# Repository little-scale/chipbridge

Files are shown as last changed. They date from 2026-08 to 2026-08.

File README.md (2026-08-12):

# Chipbridge

Chipbridge is a shared RP2040-based MIDI and synchronisation interface for
retro-console music systems. A common RP2040-Zero board provides USB MIDI,
opto-isolated serial MIDI, status indication, and a protected two-wire console
interface. Console-specific cables and passive adapters connect that interface
to supported systems.

This repository owns the shared Chipbridge hardware and RP2040 firmware. Atari
Lynx and Atari 2600 firmware remain in their respective software projects; this
repository contains only their applicable shared hardware and adapters.

## Compatibility

In this table, **Sync** means synchronisation from MIDI Clock. **Notes** means
MIDI note events are delivered to the relevant tracker channel or instrument
inputs.

| Console | Software | Sync | Notes | PCB | Firmware | Control input | Test |
|---|---|---:|---:|---|---|---|---|
| Sega Master System | [SMSGGDJ tracker](https://github.com/little-scale/smsggdj) | Yes | Yes | Shared | Shared | Sega 9-pin | OK |
| Mega Drive / Genesis | [genmddj tracker](https://github.com/little-scale/genmddj) | Yes | Yes | Shared | Shared | Sega 9-pin | OK |
| Game Gear | [SMSGGDJ tracker](https://github.com/little-scale/smsggdj) | Yes | Yes | Shared | Shared | Game Gear sync PCB | OK |
| Atari Lynx | [alynxdj tracker](https://github.com/little-scale/alynxdj) | Yes | Yes | Shared | Target-specific | 2.5 mm cable | OK |
| Super Nintendo | [SNDJ tracker](https://github.com/little-scale/sndj) | Yes | No | Shared | Shared | SNES cable | OK |
| Atari 2600 | [a26f-neo interface](https://github.com/little-scale/a26f-neo) | No | Yes | Shared | Target-specific | Atari 9-pin PCB | OK |

“Shared” means the component is maintained in Chipbridge. Target-specific
firmware remains in its console software project. See the
[`compatibility notes`](docs/COMPATIBILITY.md) for the ownership boundary.

For Wi-Fi Ableton Link rather than wired MIDI, see the complementary
[SMSGGDJ Link ESP32 bridge](https://github.com/little-scale/smsggdj-link-esp32).

## Repository layout

- `firmware/rp2040/` — shared Pico-family firmware and build instructions.
- `hardware/main/` — the RP2040-Zero Chipbridge board; see the
  [bill of materials](hardware/BOM.md).
- `hardware/adapters/` — console connector and cable adapter PCBs.
- `docs/` — MIDI protocol, serial-MIDI circuit, and wiring documentation.
- `releases/rp2040/` — current prebuilt UF2 images.
- `tests/` — host-side protocol/parser tests.
- `tools/` — reproducible release builders.

## Licensing

- Hardware designs: CERN-OHL-P-2.0.
- Firmware, tools, tests, and corresponding UF2 binaries: GPL-2.0-only.
- Documentation: CC BY 4.0.

See [`LICENSE.md`](LICENSE.md) for the precise scope, attribution, and licence
texts.

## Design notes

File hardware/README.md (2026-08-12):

# Chipbridge hardware

## Projects

- `main/` — shared RP2040-Zero Chipbridge board.
- `adapters/game-gear/` — Game Gear EXT-port adapter.
- `adapters/sega-9pin/` — Sega 9-pin controller-port adapter.
- `adapters/atari-9pin/` — Atari 9-pin adapter.

Each directory contains the editable KiCad project, schematic, and PCB layout.
KiCad automatic backups, lock files, history, and per-user project state are
intentionally excluded.

## Bill of materials

See the [Chipbridge bill of materials](BOM.md) for the main board and adapter
parts lists. Price-free CSV exports are also provided alongside each KiCad
project. The component properties in the schematics are the source of truth.

## Project-local libraries

The main board uses a custom Waveshare RP2040-Zero symbol and footprint under
`libraries/`. Its `sym-lib-table` and `fp-lib-table` use `${KIPRJMOD}` relative
paths while retaining the original library nicknames used by the schematic and
PCB. No global or user-specific KiCad library entry is required.

The adapter projects currently use standard KiCad libraries only.

## Licensing

The KiCad schematics, PCB layouts, and project-local hardware libraries in
this directory are licensed under the permissive
[CERN Open Hardware Licence Version 2 – Permissive](LICENSE-CERN-OHL-P-2.0.txt),
SPDX identifier `CERN-OHL-P-2.0`.

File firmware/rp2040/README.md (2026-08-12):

# Chipbridge RP2040 firmware

The firmware source is licensed under GPL-2.0-only; see
[`../LICENSE-GPL-2.0.txt`](../LICENSE-GPL-2.0.txt).

This Arduino sketch supports:

- Raspberry Pi Pico (RP2040)
- Raspberry Pi Pico 2 (RP2350)
- Raspberry Pi Pico 2W (RP2350; Wi-Fi is deliberately unused)
- Waveshare RP2040-Zero
- Seeed XIAO RP2040

It is a wired MIDI device, not an Ableton Link client. MIDI can arrive as
class-compliant USB MIDI from a computer/DAW or as opto-isolated five-pin
DIN/TRS MIDI on an RX-only serial input. The general firmware in
`releases/rp2040/` contains both wire roles:

- MIDI Clock plus Start/Continue/Stop drives the rolling 2-bit `SYNC: IN24`
  counter.
- A MIDI channel message switches the same pins to the flag-framed,
  console-clocked stream used by `SYNC: MIDI`. Note on/off, CC, program change,
  pitch bend, and panic are forwarded.

While in takeover, continued console CLK polling keeps that role latched even
when a note is held and no new MIDI bytes arrive. If both channel traffic and
console polling stop for 500 ms, the firmware safely returns to the counter.

## Pinout

The pinout intentionally matches the **non-inverted logic output** documented
in `sms_tracker/adapter`:

| Board | counter bit 0 / takeover CLK | counter bit 1 / takeover DAT | Ground | Game Gear EXT / Sega DE-9 |
|---|---|---|---|---|
| Raspberry Pi Pico | GP0, physical pin 1 | GP1, physical pin 2 | physical pin 3 or any GND | pins 9 / 7 / 8 |
| Raspberry Pi Pico 2 | GP0, physical pin 1 | GP1, physical pin 2 | physical pin 3 or any GND | pins 9 / 7 / 8 |
| Raspberry Pi Pico 2W | GP0, physical pin 1 | GP1, physical pin 2 | physical pin 3 or any GND | pins 9 / 7 / 8 |
| Waveshare RP2040-Zero | GP0 | GP1 | any GND | pins 9 / 7 / 8 |
| Seeed XIAO RP2040 | D6 / GP0 | D7 / GP1 | GND | pins 9 / 7 / 8 |

In the final column, pin 9 is PC5/TR (bit 0/CLK), pin 7 is PC6/TH
(bit 1/DAT), and pin 8 is ground.

Serial MIDI receiver output pins:

| Board | Opto-isolated MIDI receiver OUT |
|---|---|
| Pico / Pico 2 / Pico 2W | GP13, physical pin 17 |
| Waveshare RP2040-Zero | GP13 / header pad 14 |
| XIAO RP2040 | D3 / GP29 |

Use a 3.3 V-compatible, non-inverted MIDI-IN receiver. Do not connect a DIN or
TRS socket directly to the GPIO. Full DIN and TRS Type A wiring is in
[`../../docs/SERIAL_MIDI.md`](../../docs/SERIAL_MIDI.md).

GP13 is not a hardware-UART RX mux position, so Pico, Pico 2, Pico 2W, and
RP2040-Zero builds receive MIDI there with the Arduino-Pico core's PIO UART.
XIAO RP2040 uses hardware UART0 on D3/GP29.

### Firmware-alive LED

GP7 drives an optional external status LED on every Pico-family build. It turns
on after firmware setup completes. Received USB or serial channel MIDI makes it
pulse off briefly; MIDI Clock produces one inverse pulse per quarter note:

```text
GP7 ---- 1K ---- LED anode
                  LED cathode ---- GND
```

On a standard Pico/Pico 2/Pico 2W, GP7 is physical pin 10. On RP2040-Zero it is
header pad 8, and on XIAO RP2040 it is D5/GP7. A high-efficiency LED and 1 kΩ
resistor keep the GPIO load low. This is a firmware indicator rather than a
direct power LED: it remains off if setup does not finish.

## Universal TRS console-data interface

Do not connect a console's 5 V signal directly to GP0 or GP1. Each TRS data
line passes through a 470 Ω series resistor and then a BAT46 clamp at the
GPIO-side node:

```text
TRS tip  / DATA0 ---- 470R ----+---- GP0
                               +---- BAT46 anode
                                     BAT46 band/cathode ---- 3V3

TRS ring / DATA1 ---- 470R ----+---- GP1
                               +---- BAT46 anode
                                     BAT46 band/cathode ---- 3V3

TRS sleeve ------------------------- GND
```

The firmware never actively drives a high. In both counter and takeover roles,
logic 0 drives the GPIO low and logic 1 switches it to high impedance so the
console-side pull-up supplies high. In takeover, GP0 is fully released for the
console-owned CLK while GP1 continues to drive-low/release-high for DAT.

Power the Pico from USB before powering the console. Do not carry console +5 V
through the TRS cable, and do not hot-plug the console-data jack. The passive
console cable maps tip/ring/sleeve to the connector pins listed in
[`../../docs/WIRING.md`](../../docs/WIRING.md#universal-trs-console-data-connection).

For the Game Gear, pin 6 may remain disconnected. SMSGGDJ reads counter bit 0
as PC4 AND PC5, and the unconnected PC4 input is pulled high.

## Ready-to-use UF2 builds

The general images below contain both `SYNC: IN24` clock and `SYNC: MIDI`
takeover support.

Choose the file that exactly matches the board. Pico and Pico 2 firmware is not
interchangeable:

| Hardware | Ready-to-flash firmware |
|---|---|
| Raspberry Pi Pico | [`chipbridge-pico.uf2`](../../releases/rp2040/chipbridge-pico.uf2) |
| Raspberry Pi Pico 2 | [`chipbridge-pico2.uf2`](../../releases/rp2040/chipbridge-pico2.uf2) |
| Raspberry Pi Pico 2W | [`chipbridge-pico2w.uf2`](../../releases/rp2040/chipbridge-pico2w.uf2) |
| Waveshare RP2040-Zero | [`chipbridge-rp2040-zero.uf2`](../../releases/rp2040/chipbridge-rp2040-zero.uf2) |
| Seeed XIAO RP2040 | [`chipbridge-xiao-rp2040.uf2`](../../releases/rp2040/chipbridge-xiao-rp2040.uf2) |

The SHA-256 hashes are in
[`SHA256SUMS.txt`](../../releases/rp2040/SHA256SUMS.txt). These files were built
with Arduino-Pico core 5.5.1 using the default Pico SDK USB stack.

Regenerate all five unified images with `tools/make-pico-release.sh`. The script
passes the automatic runtime role explicitly and refreshes `SHA256SUMS.txt`.

To flash a Pico/Pico 2/Pico 2W:

1. Disconnect USB.
2. Hold **BOOTSEL** while reconnecting USB.
3. Release BOOTSEL when the `RPI-RP2`/RP2350 boot drive appears.
4. Copy the matching UF2 onto that drive. The board reboots automatically.

For XIAO RP2040, hold **B** while connecting USB, then copy its matching UF2 to
the mounted boot drive.

## Build

Install Arduino IDE 2 or `arduino-cli`, then install Earle Philhower's
**Raspberry Pi Pico/RP2040/RP2350** core. Open
`chipbridge/chipbridge.ino` and select the relevant board:

| Hardware | Arduino board |
|---|---|
| Pico | Raspberry Pi Pico |
| Pico 2 | Raspberry Pi Pico 2 |
| Pico 2W | Raspberry Pi Pico 2W |
| RP2040-Zero | Waveshare RP2040 Zero |
| XIAO RP2040 | Seeed XIAO RP2040 |

The default **Pico SDK USB stack** is supported. Build/upload normally. For a
command-line build:

```sh
arduino-cli compile --fqbn rp2040:rp2040:rpipico firmware/rp2040/chipbridge
arduino-cli compile --fqbn rp2040:rp2040:rpipico2 firmware/rp2040/chipbridge
arduino-cli compile --fqbn rp2040:rp2040:rpipico2w firmware/rp2040/chipbridge
arduino-cli compile --fqbn rp2040:rp2040:waveshare_rp2040_zero firmware/rp2040/chipbridge
arduino-cli compile --fqbn rp2040:rp2040:seeed_xiao_rp2040 firmware/rp2040/chipbridge
```

On a Pico-style board, hold BOOTSEL while plugging it in. On XIAO RP2040, hold
the **B** button while connecting USB (or use its reset/boot procedure). Copy
the generated UF2 to the mounted drive, or upload from Arduino normally. The
firmware enumerates as **Chipbridge** with a MIDI interface named
**Chipbridge MIDI**.

## Use

For clock sync with the general image:

1. Select `SYNC: IN24` in SMSGGDJ/genmddj.
2. Route MIDI Clock and transport to `Chipbridge MIDI`.
3. Press play on the tracker so it waits, then start the DAW.

For MIDI takeover with that same general image:

1. Select `SYNC: MIDI` in the tracker.
2. Route channel-voice MIDI to the bridge over USB or DIN/TRS. SMSGGDJ maps channels 1–4 to its
   four PSG voices.
3. The first channel message switches the wire into takeover. The tracker CLK
   polling keeps it there until `SYNC: MIDI` is no longer active.

Do not send MIDI Clock and channel-voice data at the same time; the two console
wire roles are mutually exclusive. Use USB MIDI **or** serial MIDI, not both at
once. To make a fixed Instrument build manually, compile with
`BRIDGE_WIRE_ROLE=BRIDGE_ROLE_MIDI_ONLY`. A diagnostic clock-only build remains available with
`BRIDGE_WIRE_ROLE=BRIDGE_ROLE_CLOCK_ONLY`.

## Verification status

The RP2040-Zero hardware has been exercised with SMS, Mega Drive / Genesis,
Game Gear, Atari Lynx, SNES, and Atari 2600 targets. See the current
[`compatibility matrix`](../../docs/COMPATIBILITY.md) for the capability and
firmware ownership boundary.

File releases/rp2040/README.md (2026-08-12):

# Pico-family firmware releases

These UF2 binaries are distributed under GPL-2.0-only with their corresponding
source under [`../../firmware/rp2040/`](../../firmware/rp2040/).

Ready-to-flash unified USB/serial-MIDI bridge firmware. Each image supports
MIDI Clock plus transport through the `SYNC: IN24` counter and automatically
switches channel-voice messages to the console-clocked `SYNC: MIDI` takeover
protocol. They enumerate as `Chipbridge` with a `Chipbridge MIDI` port.

Every build supports an optional firmware-alive/activity LED on GP7 through a
1 kΩ series resistor. It turns on after setup, pulses off for channel MIDI, and
pulses once per quarter note while receiving MIDI Clock.

| Hardware | Firmware |
|---|---|
| Raspberry Pi Pico | [`chipbridge-pico.uf2`](chipbridge-pico.uf2) |
| Raspberry Pi Pico 2 | [`chipbridge-pico2.uf2`](chipbridge-pico2.uf2) |
| Raspberry Pi Pico 2W | [`chipbridge-pico2w.uf2`](chipbridge-pico2w.uf2) |
| Waveshare RP2040-Zero | [`chipbridge-rp2040-zero.uf2`](chipbridge-rp2040-zero.uf2) |
| Seeed XIAO RP2040 | [`chipbridge-xiao-rp2040.uf2`](chipbridge-xiao-rp2040.uf2) |

These images were built with Arduino-Pico core 5.5.1 using the default Pico SDK
USB stack. Verify downloaded files with [`SHA256SUMS.txt`](SHA256SUMS.txt).
They are generated by
[`../../tools/make-pico-release.sh`](../../tools/make-pico-release.sh), which
explicitly selects the automatic runtime role.
The serial MIDI RX pin and required opto-isolated receiver are documented in
[`../../docs/SERIAL_MIDI.md`](../../docs/SERIAL_MIDI.md).

Choose the image that exactly matches the board. Pico and Pico 2 firmware is
not interchangeable.

Fixed-role diagnostic images can be produced from the same source with the
compile-time wire-role setting described in the firmware README.

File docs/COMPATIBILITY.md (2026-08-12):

# Compatibility

This matrix records the currently tested Chipbridge hardware capabilities.
"Shared firmware" means the common RP2040 firmware in this repository. Target-
specific firmware remains with the target software project.

| Console | Software | Sync | Notes | PCB | Firmware | Control input | Test |
|---|---|---:|---:|---|---|---|---|
| Sega Master System | [SMSGGDJ tracker](https://github.com/little-scale/smsggdj) | Yes | Yes | Shared | Shared | Sega 9-pin | OK |
| Mega Drive / Genesis | [genmddj tracker](https://github.com/little-scale/genmddj) | Yes | Yes | Shared | Shared | Sega 9-pin | OK |
| Game Gear | [SMSGGDJ tracker](https://github.com/little-scale/smsggdj) | Yes | Yes | Shared | Shared | Game Gear sync PCB | OK |
| Atari Lynx | [alynxdj tracker](https://github.com/little-scale/alynxdj) | Yes | Yes | Shared | Target-specific | 2.5 mm cable | OK |
| Super Nintendo | [SNDJ tracker](https://github.com/little-scale/sndj) | Yes | No | Shared | Shared | SNES cable | OK |
| Atari 2600 | [a26f-neo interface](https://github.com/little-scale/a26f-neo) | No | Yes | Shared | Target-specific | Atari 9-pin PCB | OK |

## Ownership boundary

- Chipbridge owns the shared RP2040-Zero hardware, electrical interface,
  adapter PCBs, shared firmware, and shared protocol documentation.
- [`alynxdj`](https://github.com/little-scale/alynxdj) owns its Lynx-specific
  Chipbridge firmware and console protocol.
- [`a26f-neo`](https://github.com/little-scale/a26f-neo) owns its Atari
  2600-specific Chipbridge firmware and console
  protocol.
- Console tracker projects own their console-side receivers and behaviour.

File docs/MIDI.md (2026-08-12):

# Chipbridge MIDI and sync wire protocol

Chipbridge presents two mutually exclusive behaviours on the same protected
two-wire console connection:

- MIDI Clock and transport drive a rolling 2-bit sync counter.
- MIDI channel messages engage console-clocked note takeover.

The common RP2040 firmware selects the role automatically. A fixed role can be
chosen at compile time for diagnostics. Console-side receivers remain in their
respective tracker projects.

## Electrical contract

The logical connection is `DATA0`, `DATA1`, and ground. Outputs are open-drain:
logic 0 pulls the wire low and logic 1 releases it to the console-side pull-up.
The series-resistor and BAT46 clamp interface is documented in `WIRING.md`.

| Role | DATA0 | DATA1 |
|---|---|---|
| Counter | bridge output, counter bit 0 | bridge output, counter bit 1 |
| Takeover | console output, `CLK` | bridge output, `DAT` |

## Clock and transport counter

MIDI Timing Clock (`0xF8`) is 24 PPQN. While transport is running, each clock
increments a rolling counter modulo four and presents its two bits on DATA0 and
DATA1. Start resets the counter and begins counting; Continue resumes; Stop
freezes it; System Reset clears and stops it.

The receiving console samples the counter once per video frame and advances by
the modulo-four delta. It therefore counts elapsed ticks instead of relying on
the exact timing of a GPIO edge.

## MIDI takeover transfer

The console is the clock master:

- `CLK` idles low. The console raises it and samples `DAT` on the rising edge.
- After sampling, the console lowers `CLK`.
- The bridge presents the next `DAT` bit from the falling-edge handler.
- Data is sent most-significant bit first.

After an idle gap, the bridge presents a leading flag bit:

- `0` means the queue is empty and the console stops polling.
- `1` means a fixed three-byte event follows.

```text
[flag=1] [status] [data1] [data2]    25 bits total
[flag=1] [status] [data1] [data2]    next queued event
[flag=0]                              queue empty
```

`status = type << 4 | MIDI channel`, where the channel is 0–15:

| Type | Value | Payload |
|---|---:|---|
| Note Off | 1 | note, release velocity |
| Note On | 2 | note, velocity |
| Control Change | 3 | controller, value |
| Program Change | 4 | program, zero |
| Pitch Bend | 5 | LSB, MSB |
| Panic | 7 | zero, zero |

The bridge converts Note On with velocity zero to Note Off and CC 120/123 to
Panic. Repeated unread changes for the same controller are coalesced to their
latest value. Polyphonic aftertouch and channel pressure are not forwarded.

Each console decides which channels and event types it implements. SMSGGDJ
maps MIDI channels 1–4 to its four PSG tracks; genmddj provides its own wider
voice mapping. Target-specific firmware and protocol interpretation for Atari
Lynx and Atari 2600 remain in their respective projects.

## Idle-gap and queue invariant

Loading a frame removes it from the event queue. If an idle gap occurs while a
loaded frame still has bits remaining, the bridge must preserve that frame.
Resetting the shift register during the gap would discard isolated events that
have already been removed from the queue.

The current RP2040 implementation uses a 32-event queue and a 1.5 ms idle-gap
threshold. Queue overflow is recoverable for release events by scheduling a
channel Panic, but the protocol has no acknowledgement, checksum, or retry.
Those would require coordinated changes to both the bridge and console-side
receivers.

## Automatic role arbitration

A normalised channel message is queued before takeover is engaged, allowing the
leading data-ready flag to be presented immediately. Automatic mode returns to
the counter only after both MIDI channel traffic and console polling have been
quiet for 500 ms. Active console polling therefore keeps takeover engaged even
while a note is held and no new MIDI bytes arrive.

MIDI Clock and channel messages should not be sent to the same bridge port at
the same time: counter and takeover roles are intentionally exclusive on the
two-wire connection.

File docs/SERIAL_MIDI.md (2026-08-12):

# Five-pin DIN and TRS MIDI input

Every firmware target accepts conventional MIDI 1.0 through a
**31,250-baud, 8-N-1 UART input**. Five-pin DIN and 3.5 mm TRS are only
different connector choices in front of the same MIDI receiver; the firmware
does not need a connector setting.

The serial input uses the same handlers as USB MIDI:

- Timing Clock, Start, Continue, Stop, and System Reset drive the clock path.
- Note On/Off, Control Change, Program Change, and Pitch Bend drive
  `SYNC: MIDI` takeover.
- Note On with velocity zero becomes Note Off; CC 120/123 becomes panic.
- Poly aftertouch, channel pressure, System Common, and SysEx are ignored.
- Running status and Real-Time bytes interleaved inside another message are
  handled correctly.

Use **one MIDI source at a time**: USB MIDI or serial MIDI. There is no
arbitration or merging between simultaneous inputs.

## Board-side RX pin

| Board | Serial MIDI receiver OUT → |
|---|---|
| Raspberry Pi Pico | GP13, physical pin 17 |
| Raspberry Pi Pico 2 | GP13, physical pin 17 |
| Raspberry Pi Pico 2W | GP13, physical pin 17 |
| Waveshare RP2040-Zero | GP13 / header pad 14 |
| Seeed XIAO RP2040 | D3 / GP29 |

Pico, Pico 2, Pico 2W, and RP2040-Zero use one PIO
state machine as an RX-only UART because GP13 is not a hardware-UART RX mux
position. XIAO RP2040 uses UART0 on D3/GP29. UART TX is unused and must not be
connected to the MIDI input connector.

## Required MIDI receiver

Do not connect DIN or TRS pins directly to an MCU GPIO. MIDI DIN/TRS is a
current-loop interface and its input is required to be optically isolated. Use
a standards-compliant MIDI-IN receiver circuit or module whose logic output is:

- **3.3 V compatible**;
- **non-inverted**;
- idle high; and
- fast enough for MIDI's 31,250-baud data.

Connect its logic side according to the receiver part's supply requirements.
The receiver output presented to the board RX pin must be pulled up to 3.3 V:

```text
MIDI-IN receiver VCC  -> its specified supply (5V/VBUS for 6N138)
MIDI-IN receiver GND  -> board GND
MIDI-IN receiver OUT  -> board RX pin and pull-up to board 3V3
```

The optocoupler's connector side remains isolated. Do not join DIN pin 2 or a
TRS sleeve to board logic ground unless the particular compliant receiver
design explicitly specifies a shield/chassis connection.

### Exact TRS Type A receiver using a 6N138

This follows Paul Stoffregen's 6N138 MIDI-input circuit: the 6N138 runs from
5 V, pin 6 is pulled up to the MCU's 3.3 V rail through 470 ohms, and pin 7 is
left open. This is the concrete circuit for a Waveshare RP2040-Zero. It also
works with the other boards when `GP13` is replaced by that board's RX pin from
the table above.

Parts:

- one 3.5 mm TRS female socket;
- one 6N138 optocoupler;
- `R1`: 220 ohm, 1/4 W;
- `R2`: 470 ohm;
- `D1`: 1N4148 or 1N914 reverse-protection diode;
- `C1`: 100 nF ceramic decoupling capacitor.

A BAT46, BAT48, or 1N5819 can be used for `D1` if that is what is available.
The diode's **banded cathode end must face 6N138 pin 2**.

Start at the TRS socket and wire it in this order:

```text
TRS Type A RING ---- R1 220R ----+---- 6N138 pin 2 (LED anode)
                                 |
                                 +----|<|----+
                                      D1     |
TRS Type A TIP ------------------------------+---- 6N138 pin 3 (LED cathode)

TRS SLEEVE: leave electrically unconnected
```

`D1` is directly across 6N138 pins 2 and 3, opposite to the internal LED:

```text
D1 cathode / band -> pin 2
D1 anode          -> pin 3
```

Then wire the isolated logic side:

```text
RP2040-Zero 5V/VBUS -------- 6N138 pin 8 (VCC)
RP2040-Zero GND ------------ 6N138 pin 5 (GND)

RP2040-Zero 3V3 --- R2 470R ----+--- 6N138 pin 6 (OUT)
                               |
                               +--- RP2040-Zero GP13 (serial MIDI RX)

6N138 pin 7 (BASE): no connection

C1 100nF directly between 6N138 pin 8 and pin 5
6N138 pins 1 and 4: no connection
```

The 6N138 DIP pin numbers, viewed from above with its notch at the top, are:

```text
             notch
          +--- U ---+
      NC 1|         |8 VCC -> 5V/VBUS
   anode 2|  6N138  |7 base -> no connection
 cathode 3|         |6 OUT  -> GP13 and 470R -> 3V3
      NC 4|         |5 GND  -> board GND
          +---------+
```

Do not connect TRS sleeve to RP2040-Zero GND. The 6N138 input side—pins 2 and
3—must have no DC connection to the RP2040 side. Power the RP2040-Zero from
USB; its `5V/VBUS` pin supplies the 6N138, while the separate `3V3` pull-up
guarantees that GP13 never receives a 5 V logic high.

With no MIDI cable activity, GP13 should measure approximately 3.3 V. During
MIDI data it switches between approximately 3.3 V and 0 V. A multimeter will
usually show only an average; use a logic analyser or oscilloscope to see the
31,250-baud pulses.

### Five-pin DIN input

Use a 180-degree five-pin DIN **female** MIDI-IN connector wired to the receiver
according to its schematic:

| DIN contact | MIDI role |
|---|---|
| pin 4 | current source |
| pin 5 | current sink |
| pin 2 | cable shield |
| pins 1 and 3 | no connection |

Be careful with connector drawings: pin order reverses between the mating face
and solder side. Follow the pin numbers moulded into the connector.

### TRS MIDI input

Use the MIDI Association's standardized **TRS Type A** mapping:

| TRS contact | Equivalent DIN contact |
|---|---|
| Tip | pin 5, current sink |
| Ring | pin 4, current source |
| Sleeve | pin 2, shield |

Type B swaps tip and ring and is not the documented wiring here. A Type-B
source can still be used with a Type-B-to-DIN adapter feeding the five-pin
input.

DIN and TRS sockets may both be fitted ahead of one receiver, but connect only
one MIDI source at a time. Two active outputs must never be tied together.

## Console connection is unchanged

The serial MIDI connector is the **input side of the bridge**. The Game Gear
EXT / Sega DE-9 connection remains the non-inverted two-wire interface in
[`WIRING.md`](WIRING.md):

- connector pin 9 = counter bit 0 / takeover CLK;
- connector pin 7 = counter bit 1 / takeover DAT;
- connector pin 8 = shared console ground.

The MIDI receiver and the console BAT46 protection network are separate
circuits.

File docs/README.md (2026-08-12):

# Chipbridge documentation

The documentation in this directory is licensed under the
[Creative Commons Attribution 4.0 International licence](LICENSE-CC-BY-4.0.txt).

When redistributing or adapting it, credit **“Chipbridge documentation by
little-scale contributors”** and link to the Chipbridge repository where
practical.

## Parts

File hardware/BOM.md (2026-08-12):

# Chipbridge bill of materials

This bill of materials covers one populated Chipbridge main board and the
optional console adapter boards. Prices are intentionally omitted because they
vary by supplier, quantity, region, and date.

The KiCad schematic properties are the source of truth. The CSV files are
exported views for builders and sourcing:

- [Main board BOM](main/BOM.csv)
- [Game Gear adapter BOM](adapters/game-gear/BOM.csv)
- [Sega 9-pin adapter BOM](adapters/sega-9pin/BOM.csv)
- [Atari 9-pin adapter BOM](adapters/atari-9pin/BOM.csv)

Quantities below are per PCB. A dash in the MPN column means the part is
generic and may be substituted if the stated electrical and mechanical
requirements are met.

## Main board

| References | Qty | Part | Manufacturer | MPN | Requirements / notes |
|---|---:|---|---|---|---|
| C1 | 1 | 100 nF ceramic capacitor | — | — | 16 V minimum; 2.50 mm lead pitch; body must fit the assigned footprint |
| D1, D2 | 2 | BAT46 Schottky diode | Vishay | BAT46-TAP | DO-35 / SOD27 axial package |
| D3 | 1 | 1N4148 switching diode | onsemi | 1N4148 | DO-35 axial package |
| D4 | 1 | 3 mm indicator LED | — | — | Through-hole; observe polarity |
| J1 | 1 | Console-data 3.5 mm TRS jack | Same Sky | SJ1-3525N | Right-angle through-hole, with switching contacts |
| J2 | 1 | MIDI-input 3.5 mm TRS jack | Same Sky | SJ1-3525N | Right-angle through-hole, with switching contacts |
| R1, R2, R4, R5 | 4 | 470 ohm resistor | — | — | Axial DIN0204 body; 0.25 W or greater |
| R3 | 1 | 220 ohm resistor | — | — | Axial DIN0204 body; 0.25 W or greater |
| U1 | 1 | RP2040-Zero module | Waveshare Electronics | RP2040-ZERO | Use the Waveshare RP2040-Zero pinout and module footprint |
| U2 | 1 | High-gain optocoupler | onsemi | 6N138M | 8-pin DIP; a socket is optional and is not included |

## Game Gear adapter

| References | Qty | Part | Manufacturer | MPN | Requirements / notes |
|---|---:|---|---|---|---|
| J1 | 1 | 1x3 pin header | — | — | Vertical through-hole, 2.54 mm pitch |
| J2 | 1 | 3.5 mm TRS jack | Same Sky | SJ1-3525N | Right-angle through-hole, with switching contacts |

## Sega 9-pin adapter

| References | Qty | Part | Manufacturer | MPN | Requirements / notes |
|---|---:|---|---|---|---|
| J1 | 1 | 3.5 mm TRS jack | Same Sky | SJ1-3525N | Right-angle through-hole, with switching contacts |

## Atari 9-pin adapter

| References | Qty | Part | Manufacturer | MPN | Requirements / notes |
|---|---:|---|---|---|---|
| J1 | 1 | 3.5 mm TRS jack | Same Sky | SJ1-3525N | Right-angle through-hole, with switching contacts |

## Items not included

The BOM does not include bare PCBs, a USB-C data cable, console-specific
cables, solder, mounting hardware, or an optional DIP-8 socket for U2. The
Atari Lynx 2.5 mm cable and Super Nintendo cable are system-level items rather
than components on the published PCBs.

Before ordering, check manufacturer lifecycle status, package compatibility,
and supplier stock. Distributor order codes and dated pricing can be added to
a generated sourcing report without changing this stable BOM.

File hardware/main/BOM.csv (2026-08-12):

Reference | Qty | Value | Footprint | MPN | Manufacturer | Chosen_Distributor | Datasheet | Validated | DNP | Notes
C1 | 1 | 0.1uF | Disc_D3.4mm_W2.1mm_P2.50mm |  |  |  |  |  |  | Generic 100 nF ceramic capacitor, 16 V minimum, 2.50 mm lead pitch, body no larger than footprint
D1,D2 | 2 | BAT46 | DO-35_SOD27_P7.62mm_Horizontal | BAT46-TAP | Vishay |  | https://www.vishay.com/docs/85662/bat46.pdf
D3 | 1 | 1N4148 | DO-35_SOD27_P7.62mm_Horizontal | 1N4148 | onsemi |  | https://www.onsemi.com/pdf/datasheet/1n914-d.pdf
D4 | 1 | LED | LED_D3.0mm |  |  |  |  |  |  | Generic 3 mm through-hole indicator LED; observe polarity
J1 | 1 | CONSOLE_DATA | Jack_3.5mm_CUI_SJ1-3525N_Horizontal | SJ1-3525N | Same Sky |  | https://www.sameskydevices.com/product/resource/sj1-352xn.pdf
J2 | 1 | TRS_MIDI_IN | Jack_3.5mm_CUI_SJ1-3525N_Horizontal | SJ1-3525N | Same Sky |  | https://www.sameskydevices.com/product/resource/sj1-352xn.pdf
R2,R4,R1,R5 | 4 | 470r | Axial_DIN0204_L3.6mm_D1.6mm_P7.62mm_Horizontal |  |  |  |  |  |  | Generic 470 ohm axial resistor, 0.25 W or greater, DIN0204 body
R3 | 1 | 220r | Axial_DIN0204_L3.6mm_D1.6mm_P7.62mm_Horizontal |  |  |  |  |  |  | Generic 220 ohm axial resistor, 0.25 W or greater, DIN0204 body
U1 | 1 | RP2040-ZERO | MODULE_RP2040-ZERO | RP2040-ZERO | Waveshare Electronics |  | https://www.waveshare.com/wiki/RP2040-Zero
U2 | 1 | 6N138 | DIP-8_W7.62mm_Socket | 6N138M | onsemi |  | https://www.onsemi.com/download/data-sheet/pdf/hcpl2731m-d.pdf |  |  | 8-pin DIP optocoupler; a DIP-8 socket is optional and is not included in this BOM

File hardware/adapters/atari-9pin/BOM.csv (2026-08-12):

Reference | Qty | Value | Footprint | MPN | Manufacturer | Chosen_Distributor | Datasheet | Validated | DNP | Notes
J1 | 1 | AudioJack3_SwitchTR | Jack_3.5mm_CUI_SJ1-3525N_Horizontal | SJ1-3525N | Same Sky |  | https://www.sameskydevices.com/product/resource/sj1-352xn.pdf

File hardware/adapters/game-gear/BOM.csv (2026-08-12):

Reference | Qty | Value | Footprint | MPN | Manufacturer | Chosen_Distributor | Datasheet | Validated | DNP | Notes
J1 | 1 | Conn_01x03_Pin | PinHeader_1x03_P2.54mm_Vertical |  |  |  |  |  |  | Generic 1x3 vertical through-hole pin header, 2.54 mm pitch
J2 | 1 | AudioJack3_SwitchTR | Jack_3.5mm_CUI_SJ1-3525N_Horizontal | SJ1-3525N | Same Sky |  | https://www.sameskydevices.com/product/resource/sj1-352xn.pdf

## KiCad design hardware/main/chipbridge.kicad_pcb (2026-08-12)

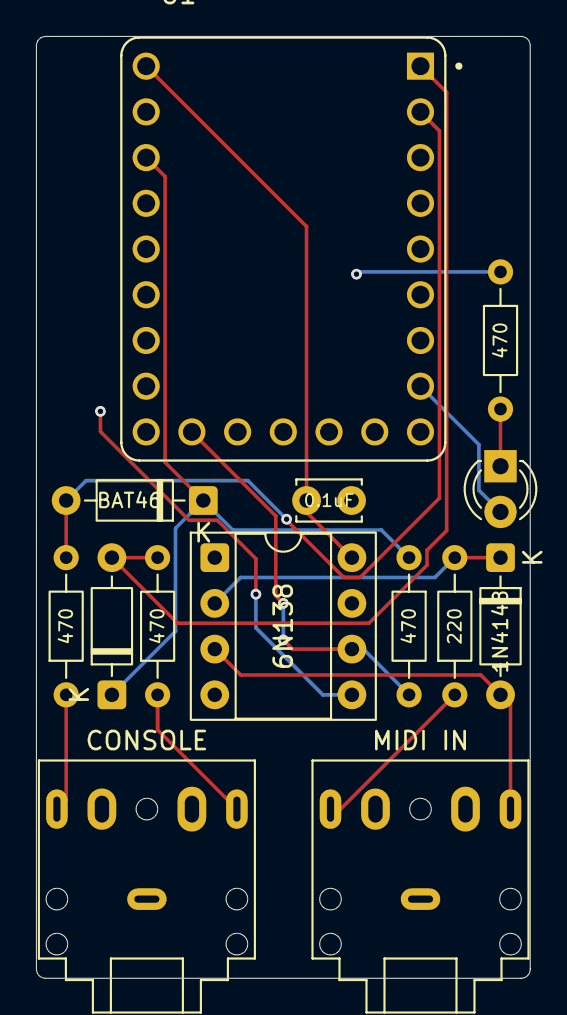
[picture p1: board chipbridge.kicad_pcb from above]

Board: 2 copper layers, 27.4 x 52.3 mm, 14 parts (0 on the bottom side), 13 nets.

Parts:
C1: 0.1uF; C_Disc_D3.4mm_W2.1mm_P2.50mm
CONSOLE: CONSOLE_DATA; Jack_3.5mm_CUI_SJ1-3525N_Horizontal
D1, D2: BAT46; D_DO-35_SOD27_P7.62mm_Horizontal
D3: 1N4148; D_DO-35_SOD27_P7.62mm_Horizontal
D4: LED; LED_D3.0mm
MIDI IN: TRS_MIDI_IN; Jack_3.5mm_CUI_SJ1-3525N_Horizontal
R1, R2, R4, R5: 470; R_Axial_DIN0204_L3.6mm_D1.6mm_P7.62mm_Horizontal
R3: 220; R_Axial_DIN0204_L3.6mm_D1.6mm_P7.62mm_Horizontal
U1: RP2040-ZERO; MODULE_RP2040-ZERO
U2: 6N138; DIP-8_W7.62mm_Socket

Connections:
+3V3: D1.1 (K), D2.1 (K), R4.1, U1.21 (3V3)
+5V: C1.1, U1.23 (5V), U2.8 (VCC)
/DATA0: CONSOLE.T, R1.1
/DATA1: CONSOLE.R, R2.1
/MIDI_DATA: R4.2, U1.14 (GP13), U2.6 (VO2)
GND: C1.2, CONSOLE.S, R5.1, U1.22 (GND), U2.5 (GND)
unnamed: D1.2 (A), R1.2, U1.1 (GP0)
unnamed: D2.2 (A), R2.2, U1.2 (GP1)
unnamed: D3.2 (A), MIDI IN.T, U2.3 (C2)
unnamed: D3.1 (K), R3.2, U2.2 (C1)
unnamed: D4.2 (A), U1.8 (GP7)
unnamed: D4.1 (K), R5.2
unnamed: MIDI IN.R, R3.1

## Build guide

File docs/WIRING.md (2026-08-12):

# Bridge wiring — SMS / Mega Drive DE-9 and Game Gear EXT

Every target uses the same **non-inverted logical mapping** documented by
`sms_tracker`: connector pin 9 is counter bit 0 / takeover CLK, connector pin 7
is counter bit 1 / takeover DAT, and pin 8 is ground. The bridge presents a
rolling 2-bit counter `presented & 3`; a high line is logical 1 and a low line
is logical 0.

## Board pinout and capability matrix

| Board | bit 0 / CLK → connector pin 9 | bit 1 / DAT → connector pin 7 | Ground → pin 8 | Serial MIDI RX | Firmware capability |
|---|---|---|---|---|---|
| **Raspberry Pi Pico** | GP0, physical pin 1 | GP1, physical pin 2 | physical pin 3 or any GND | GP13, physical pin 17 | USB + serial MIDI |
| **Raspberry Pi Pico 2** | GP0, physical pin 1 | GP1, physical pin 2 | physical pin 3 or any GND | GP13, physical pin 17 | USB + serial MIDI |
| **Raspberry Pi Pico 2W** | GP0, physical pin 1 | GP1, physical pin 2 | physical pin 3 or any GND | GP13, physical pin 17 | USB + serial MIDI; onboard Wi-Fi unused |
| **Waveshare RP2040-Zero** | GP0 | GP1 | GND | GP13 / header pad 14 | USB + serial MIDI |
| **Seeed XIAO RP2040** | D6 / GP0 | D7 / GP1 | GND | D3 / GP29 | USB + serial MIDI |

### Optional RP2040 firmware-alive LED

All Pico-family builds use GP7 for an optional active-high status LED. Connect
GP7 through a 1 kΩ resistor to the LED anode and connect its cathode to GND.
The firmware turns it on only after setup completes:

| Board | Status LED GPIO |
|---|---|
| Pico / Pico 2 / Pico 2W | GP7, physical pin 10 |
| RP2040-Zero | GP7, header pad 8 |
| XIAO RP2040 | D5 / GP7 |

## Universal TRS console-data connection

The bridge exposes one non-inverted, bidirectional two-wire contract. Use this
same mapping on every bridge board:

| TRS contact | Logical signal | RP2040-family example |
|---|---|---|
| Tip | `DATA0` / counter bit 0 / takeover `CLK` | GP0 |
| Ring | `DATA1` / counter bit 1 / takeover `DAT` | GP1 |
| Sleeve | shared ground | GND |

The connector is data **I/O**, not an audio socket and not the TRS MIDI input.
In counter mode the bridge owns both signals. In MIDI takeover, the console
owns DATA0/CLK and the bridge owns DATA1/DAT.

All bridge outputs use open-drain semantics: logic 0 pulls low and logic 1
releases the wire. Each line uses the current-limited BAT46 clamp shown below
instead of a separate level-shifter IC:

```text
TRS tip  / DATA0 ---- 470R ----+---- MCU DATA0 GPIO
                               |
                               +---- BAT46 anode
                                     BAT46 band/cathode ---- MCU 3V3

TRS ring / DATA1 ---- 470R ----+---- MCU DATA1 GPIO
                               |
                               +---- BAT46 anode
                                     BAT46 band/cathode ---- MCU 3V3

TRS sleeve ------------------------- MCU GND
```

The series resistor limits current when a console presents a 5 V high; the
Schottky diode clamps the GPIO-side node near the 3.3 V rail. Power the bridge
from USB whenever the console is powered so a console cannot back-power an
unpowered MCU through a clamp diode. Console +5 V is not carried through the
TRS cable.

Do not hot-plug the TRS console-data cable. TRS contacts can momentarily short
tip or ring to ground during insertion.

Console-specific cables are passive pin converters:

| Adapter | TRS tip / DATA0 | TRS ring / DATA1 | TRS sleeve |
|---|---|---|---|
| Master System port 2 | DE-9 pin 9 / TR | DE-9 pin 7 / TH | DE-9 pin 8 |
| Mega Drive port 2 | DE-9 pin 9 / TR | DE-9 pin 7 / TH | DE-9 pin 8 |
| Game Gear EXT | EXT pin 9 / PC5 | EXT pin 7 / PC6 | EXT pin 8 |
| Atari 2600 port 2 | DE-9 pin 1 / Up / PA0 | DE-9 pin 2 / Down / PA1 | DE-9 pin 8 |

The Atari 2600 wire behaviour is implemented by target-specific firmware in
the `a26f-neo` project. Clearly distinguish Atari and Sega adapters: both use
DE-9 shells, but Atari pin 7 is +5 V while Sega pin 7 is TH/DATA1.

Target-specific build and usage details:

- [Pico, Pico 2, Pico 2W, RP2040-Zero, and XIAO RP2040](../firmware/rp2040/README.md)
- [Five-pin DIN and TRS Type A MIDI input](SERIAL_MIDI.md)

## SMS controller port 2 — DE-9 (console side)

A standard DE-9. Only **TR and TH are bidirectional**, which is why the protocol
is a 2-bit counter. (From `~/Documents/sms_tracker/HARDWARE.md`.)

| pin | signal | sync use |
|-----|---|---|
| 1 | Up | — (input only) |
| 2 | Down | — (input only) |
| 3 | Left | — (input only) |
| 4 | Right  | — (input only) |
| 5 | +5V | shifter HV reference only; otherwise do not connect |
| 6 | TL | leave unconnected (floats high)  |
| **7** | **TH** | **counter bit 1** |
| 8 | GND | shared ground |
| **9** | **TR** | **counter bit 0** |

The tracker reads bit 0 as `TR AND TL`; with TL left floating-high, TR alone
carries bit 0. All lines are pulled up, so an idle/unplugged port reads high
(counter = 3) — `SYNC IN` latches the line state when armed and counts only
*changes*, so a clean start requires the bridge to be presenting a stable count
before the tracker arms.

## Mega Drive / Genesis — genmddj

> ✅ **Confirmed working on Mega Drive hardware (2026-06-25)** — the bridge clocks
> genmddj over controller port 2 with no MD-side changes.

The **same bridge, same wiring, no firmware change** also clocks **genmddj** (the
Mega Drive port of SMSGGDJ). The MD shares the DE-9 controller-port family, and
genmddj's `SYNC: IN` reads the identical 2-bit counter — `$A10005` bits 5/6, i.e.
**TR (pin 9) = bit 0, TH (pin 7) = bit 1**, at 24 PPQN. Wire it exactly as the
tables above, into MD **controller port 2** (a normal pad in port 1 for editing).
In genmddj: **OPTIONS → SYNC: IN**, press Start (shows `WAIT`), then start the
Link/MIDI transport.

Two MD-specific notes:

- **TL (pin 6) is unused here.** The SMS reads bit 0 as `TR AND TL`; genmddj reads
  **TR alone** (`$A10005` bit 5), so pin 6 just stays floating (as above).
- **Check the TH (pin 7) pull-up.** ⚠ The open-drain bridge leans on the console's
  pull-ups for the high level. An idle MD port reads `$7F` (pull-ups present), so
  **TR (pin 9)** is fine — but **TH (pin 7)** is normally the MD's *select output*,
  and genmddj reconfigures it as an input (`$A1000B = 0`). If its input-mode pull-up
  is weak, counter bit 1 can read flaky — symptom: genmddj won't advance, or runs
  erratically / double-time. Fix: a **10 kΩ pull-up on pin 7** to a logic-high rail —
  the XIAO **3V3** pad (3.3 V is a valid MD logic high) or the console **+5 V (pin
  5)**. A resistor pull-up draws microamps, so this does *not* break the "don't power
  from +5 V" rule above (that rule is about the board's WiFi-peak supply current).
  One on pin 9 won't hurt either.

Counted-not-timed, so PAL/NTSC region doesn't matter — genmddj's slave locks to flat
groove-6 (24 PPQN) to match the wire. The same 3-wire cable also cross-syncs a Mega
Drive directly to an SMS / Game Gear — genmddj ↔ SMSGGDJ.

## MIDI takeover mode — same wires, different directions

> ✅ **Hardware-verified 2026-07-07** — on a **Mega Drive 2 in Master System mode**
> (+ Everdrive) driving smsggdj: USB-MIDI on ch 1–4 plays the four PSG voices live,
> bare 3-wire (no divider), with `k on` on the bridge. The *counter/clock-sync*
> direction (`SYNC: IN24`) was verified earlier (2026-07-06, incl. from a DAW's
> USB-MIDI clock). That record describes the historical test setup, not the
> universal Instrument Edition wiring below.
>
> Bring-up fixed one real bug: the bridge's idle-gap resync (`takeover_idle_check`)
> discarded a frame that had been popped from the queue but not yet clocked out,
> silently losing **isolated** note-ons/offs (bursts masked it — "you had to play
> overlapping notes to hear anything"). Fixed: only re-present when nothing is loaded.

> ⚠ **Send clock OR notes to the bridge, never both at once** — takeover (notes) and the
> counter (clock) are mutually exclusive on the two wires, auto-arbitrated by traffic.
> Notes arriving during clock-sync hijack the wire and garble `IN24`. See README →
> *Clock source* for the full rule and the `k off`/`k on`/`k auto` overrides.

MIDI takeover (`SYNC=MIDI` on the console; fixed on in an Instrument image) reuses the **same
three wires — no re-cabling**. Only the pin *directions* change, and the firmware
(`wire_set_mode`) and console flip them automatically when the mode engages:

| Line | DE-9 | Counter mode | **MIDI mode** |
|---|---|---|---|
| **CLK** | TR (pin 9) | bridge → console (counter bit 0) | **console → bridge** (clock master) |
| **DAT** | TH (pin 7) | bridge → console (counter bit 1) | **bridge → console** (data, MSB-first) |
| GND | pin 8 | shared | shared |

With the current **genmddj** build, CLK is push-pull and DAT is bridge-driven
open-drain. The series resistor and BAT46 clamp protect the bridge input from
the console's 5 V CLK high.

- **DAT (TH, pin 7)** — the bridge drives it **open-drain**, the console reads it. Its high comes
  from the console-side pull-up.
- **CLK (TR, pin 9)** — the *console* now drives it and the bridge reads it as an input.
  Its push-pull high is current-limited and clamped before the 3.3 V GPIO.

## Bench-testing the bridge (no console needed)

1. Flash the general RP2040 image and send a channel-voice message to engage
   automatic takeover, or compile a fixed MIDI-only diagnostic image.
2. Send MIDI notes/CCs from a DAW over USB.
3. **Drive CLK** (TR / GP0, through an appropriate level interface) from a bench clock or a second MCU
   emulating the console's `midi_clock_bit`: raise CLK, wait, read, lower CLK, wait
   `~MIDI_SETTLE`. **Capture DAT** (TH / GP1) on a logic analyser.
4. **Decode:** after an idle gap the bridge presents a **flag bit**; `1` → the next
   **24 bits** are `status·d1·d2` (`status = type<<4|chan`); `0` → queue empty. Confirm the
   decoded events match the MIDI you sent (NoteOn = type 2, etc.).
5. Measure falling-CLK to DAT transition time and verify DAT is stable before
   every following rising edge. Inspect the queue diagnostics in a dedicated
   diagnostic build before changing timing constants.

A full loop test with a real console validates both the responder and the
console-side poller.

## Power & ground

- Power the MCU board from its own USB supply.
- Share GND (board GND ↔ console pin 8).
- Leave console +5 V disconnected. It is not part of the three-wire TRS
  console-data contract and must never power the MCU.

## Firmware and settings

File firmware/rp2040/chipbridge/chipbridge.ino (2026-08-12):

// SPDX-License-Identifier: GPL-2.0-only
// Chipbridge wired USB/serial-MIDI firmware for Pico-family boards.
//
// The general build switches one protected two-wire connection between the
// 24-PPQN counter and the console-clocked MIDI takeover protocol. Instrument
// builds can still force takeover at compile time.
//
// Build with Earle Philhower's Arduino-Pico core. See ../README.md.

#include <Arduino.h>
#include <MIDIUSB.h>
#include <USB.h>

#include "config.h"
#include "midi_proto.h"
#include "serial_midi_parser.h"

enum WireMode {
  WIRE_COUNTER = 0,
  WIRE_TAKEOVER = 1,
};

volatile WireMode g_wireMode = WIRE_COUNTER;
volatile uint8_t g_counter = 0;
volatile bool g_playing = false;

volatile MidiEvt g_evtq[MIDI_EVTQ_SIZE];
volatile uint16_t g_eHead = 0;
volatile uint16_t g_eTail = 0;
volatile uint32_t g_shift = 0;
volatile int g_shiftBits = 0;
volatile uint32_t g_lastClkEdgeUs = 0;
volatile uint32_t g_lastChannelVoiceUs = 0;
volatile bool g_idleArmed = false;
volatile uint32_t g_dropped = 0;
// A queue overflow may evict an earlier release. Record its channel outside the
// ring so the consumer emits a recovery Panic before normal queued traffic.
volatile uint16_t g_recoveryPanicMask = 0;

uint32_t g_ledPulseStartedUs = 0;
bool g_ledPulseActive = false;
uint8_t g_midiClockLedTick = 0;

// GP7 is normally high as the firmware-alive indication. Incoming MIDI starts
// a short, non-blocking low pulse. Rate limiting keeps a clock stream visibly
// flickering instead of retriggering so quickly that the LED stays dark.
static void indicate_midi_activity() {
  const uint32_t now = micros();
  if (!g_ledPulseActive &&
      (g_ledPulseStartedUs == 0 ||
       (uint32_t)(now - g_ledPulseStartedUs) >= MIDI_LED_PERIOD_US)) {
    digitalWriteFast(PIN_STATUS_LED, LOW);
    g_ledPulseStartedUs = now;
    g_ledPulseActive = true;
  }
}

static void service_activity_led() {
  if (g_ledPulseActive &&
      (uint32_t)(micros() - g_ledPulseStartedUs) >= MIDI_LED_OFF_US) {
    digitalWriteFast(PIN_STATUS_LED, HIGH);
    g_ledPulseActive = false;
  }
}

static inline uint16_t evtq_count() {
  return (uint16_t)(g_eHead - g_eTail);
}

// GP0/GP1 are the non-inverted TRS DATA0/DATA1 pair. Every driven state uses
// low-or-release semantics so the same current-limited BAT46 interface can
// safely reverse DATA0 for console-clocked MIDI takeover.
static inline void write_open_drain(uint8_t pin, bool high) {
  const uint32_t mask = 1u << pin;
  digitalWriteFast(pin, LOW);  // the output latch is always low
  if (high) {
    sio_hw->gpio_oe_clr = mask;  // release: external LV pull-up makes logic 1
  } else {
    sio_hw->gpio_oe_set = mask;  // assert logic 0
  }
}

static inline void present_counter(uint8_t counter) {
  write_open_drain(PIN_COUNTER_BIT0, (counter & 0x01) != 0);
  write_open_drain(PIN_COUNTER_BIT1, (counter & 0x02) != 0);
}

static void load_frame_locked() {
  if (g_recoveryPanicMask != 0) {
    uint8_t channel = 0;
    while ((g_recoveryPanicMask & (1u << channel)) == 0) ++channel;
    g_recoveryPanicMask &= (uint16_t)~(1u << channel);
    MidiEvt event = {(uint8_t)((EVT_PANIC << 4) | channel), 0, 0};
    g_shift = midi_frame_word(event);
    g_shiftBits = MIDI_FRAME_BITS;
  } else if (evtq_count() != 0) {
    const uint16_t index = g_eTail++ & (MIDI_EVTQ_SIZE - 1);
    MidiEvt event;
    event.status = g_evtq[index].status;
    event.d1 = g_evtq[index].d1;
    event.d2 = g_evtq[index].d2;
    g_shift = midi_frame_word(event);
    g_shiftBits = MIDI_FRAME_BITS;
  } else {
    g_shift = 0;
    g_shiftBits = 1;  // queue-empty flag
  }
}

static inline void present_bit_locked() {
  if (g_shiftBits == 0) load_frame_locked();
  const bool bit = (g_shift & 0x80000000u) != 0;
  g_shift <<= 1;
  --g_shiftBits;
  write_open_drain(PIN_MIDI_DAT, bit);
}

// The console samples DAT on CLK's rising edge. Once it lowers CLK again, this
// ISR presents the next bit so it is stable before the following rising edge.
static void clk_falling_isr() {
  g_lastClkEdgeUs = micros();
  g_idleArmed = false;
  present_bit_locked();
}

static void takeover_idle_check() {
  const uint32_t now = micros();
  if (!g_idleArmed &&
      (uint32_t)(now - g_lastClkEdgeUs) > TAKEOVER_IDLE_US) {
    noInterrupts();
    if (!g_idleArmed) {
      g_idleArmed = true;
      // A loaded frame has already been popped from the queue. Keep it until
      // the console clocks it out; resetting here loses isolated notes.
      if (g_shiftBits == 0) present_bit_locked();
    }
    interrupts();
  }
}

// AUTO enters takeover when channel-voice MIDI arrives. It may return to the
// counter only after both MIDI traffic and console CLK polling have stopped.
// The CLK condition is important: a held note can be quiet for seconds while a
// tracker in SYNC:MIDI continues polling, and must never see GP0 become an
// output underneath it.
static bool takeover_auto_active() {
  const uint32_t now = micros();
  return (uint32_t)(now - g_lastChannelVoiceUs) <= TAKEOVER_AUTO_RELEASE_US ||
         (g_wireMode == WIRE_TAKEOVER &&
          (uint32_t)(now - g_lastClkEdgeUs) <= TAKEOVER_AUTO_RELEASE_US);
}

static void evtq_push(const MidiEvt& event, bool critical) {
  noInterrupts();

  // Collapse an unread sweep of the same controller to its latest value.
  if ((event.status & 0xF0) == (EVT_CC << 4)) {
    for (uint16_t i = g_eTail; i != g_eHead; ++i) {
      volatile MidiEvt& queued = g_evtq[i & (MIDI_EVTQ_SIZE - 1)];
      if (queued.status == event.status && queued.d1 == event.d1) {
        queued.d2 = event.d2;
        interrupts();
        return;
      }
    }
  }

  if (evtq_count() >= MIDI_EVTQ_SIZE) {
    if (!critical) {
      ++g_dropped;
      interrupts();
      return;
    }
    const MidiEvt evicted = {
      g_evtq[g_eTail & (MIDI_EVTQ_SIZE - 1)].status,
      g_evtq[g_eTail & (MIDI_EVTQ_SIZE - 1)].d1,
      g_evtq[g_eTail & (MIDI_EVTQ_SIZE - 1)].d2,
    };
    ++g_eTail;  // release events take priority over the oldest queued event
    const uint8_t evictedType = evicted.status >> 4;
    if (evictedType == EVT_NOTE_OFF || evictedType == EVT_PANIC)
      g_recoveryPanicMask |= (uint16_t)(1u << (evicted.status & 0x0F));
    ++g_dropped;
  }

  volatile MidiEvt& slot = g_evtq[g_eHead & (MIDI_EVTQ_SIZE - 1)];
  slot.status = event.status;
  slot.d1 = event.d1;
  slot.d2 = event.d2;
  ++g_eHead;
  interrupts();
}

static void wire_set_mode(WireMode mode) {
  if (mode == g_wireMode) return;

  if (mode == WIRE_TAKEOVER) {
    // Avoid contention first: the console owns CLK in takeover mode.
    sio_hw->gpio_oe_clr = 1u << PIN_MIDI_CLK;

    noInterrupts();
    g_shiftBits = 0;
    g_idleArmed = false;
    g_lastClkEdgeUs = micros();
    present_bit_locked();  // make the leading flag stable before the next poll
    interrupts();

    attachInterrupt(digitalPinToInterrupt(PIN_MIDI_CLK),
                    clk_falling_isr, FALLING);
  } else {
    detachInterrupt(digitalPinToInterrupt(PIN_MIDI_CLK));

    noInterrupts();
    // Unconsumed events belong to the takeover session being left explicitly.
    g_eTail = g_eHead;
    g_shiftBits = 0;
    g_recoveryPanicMask = 0;
    interrupts();

    present_counter(g_counter);
  }

  g_wireMode = mode;
}

static void handle_realtime(uint8_t status) {
  switch (status) {
    case 0xF8:  // Timing Clock
      if (++g_midiClockLedTick >= 24) {
        g_midiClockLedTick = 0;
        indicate_midi_activity();  // one inverse pulse per quarter note
      }
      if (g_playing) {
        g_counter = (uint8_t)((g_counter + 1u) & 0x03u);
        if (g_wireMode == WIRE_COUNTER) present_counter(g_counter);
      }
      break;
    case 0xFA:  // Start
      g_midiClockLedTick = 0;
      indicate_midi_activity();  // transport start is the initial downbeat
      g_counter = 0;
      g_playing = true;
      if (g_wireMode == WIRE_COUNTER) present_counter(g_counter);
      break;
    case 0xFB:  // Continue
      indicate_midi_activity();
      g_playing = true;
      break;
    case 0xFC:  // Stop
      indicate_midi_activity();
      g_playing = false;
      break;
    case 0xFF:  // System Reset
      g_midiClockLedTick = 0;
      indicate_midi_activity();
      g_counter = 0;
      g_playing = false;
      if (g_wireMode == WIRE_COUNTER) present_counter(g_counter);
      break;
    default:
      break;
  }
}

static void handle_channel_message(uint8_t status, uint8_t d1, uint8_t d2) {
  if (status < 0x80 || status >= 0xF0) return;

#if MIDI_TAKEOVER_ENABLED
  MidiEvt event;
  bool critical = false;
  if (midi_normalise(status & 0xF0, status & 0x0F,
                     d1, d2, event, critical)) {
    indicate_midi_activity();
    evtq_push(event, critical);
#if BRIDGE_WIRE_ROLE == BRIDGE_ROLE_AUTO
    g_lastChannelVoiceUs = micros();
    // The event is already queued, so entering takeover presents a data-ready
    // flag immediately rather than an avoidable empty poll.
    wire_set_mode(WIRE_TAKEOVER);
#endif
  }
#endif
}

static void handle_midi_packet(const midiEventPacket_t& packet) {
  const uint8_t bytes[3] = {packet.byte1, packet.byte2, packet.byte3};

  // Real-time messages normally occupy byte1 of their own packet. Scan all
  // payload positions as a defensive measure against host packet variation.
  for (unsigned i = 0; i < 3; ++i) {
    if (bytes[i] >= 0xF8) handle_realtime(bytes[i]);
  }

  handle_channel_message(packet.byte1, packet.byte2, packet.byte3);
}

static void poll_usb_midi() {
  midiEventPacket_t packet;
  do {
    packet = MidiUSB.read();
    if (packet.header != 0) handle_midi_packet(packet);
  } while (packet.header != 0);
}

static SerialMidiParser g_serialMidiParser;

#if SERIAL_MIDI_USE_PIO
// GP13 is not one of UART0's hardware RX mux positions. SerialPIO uses one PIO
// state machine so the PCB's GP13 MIDI_DATA connection remains valid at the
// standard 31,250-baud MIDI rate.
static SerialPIO g_serialMidi(NOPIN, PIN_SERIAL_MIDI_RX, 64);
#else
#define g_serialMidi Serial1
#endif

static void poll_serial_midi() {
  SerialMidiMessage message;
  while (g_serialMidi.available()) {
    const SerialMidiResult result = serial_midi_parser_feed(
        g_serialMidiParser, (uint8_t)g_serialMidi.read(), message);
    if (result == SERIAL_MIDI_REALTIME) {
      handle_realtime(message.status);
    } else if (result == SERIAL_MIDI_CHANNEL) {
      handle_channel_message(message.status, message.d1, message.d2);
    }
  }
}

void setup() {
  // Remain dark during reset/initialisation, then light once setup is complete.
  digitalWriteFast(PIN_STATUS_LED, LOW);
  pinMode(PIN_STATUS_LED, OUTPUT);

  // Start high-impedance so an already-running console can never contend with
  // the bridge during boot. The selected fixed role configures directions next.
  pinMode(PIN_COUNTER_BIT0, INPUT);
  pinMode(PIN_COUNTER_BIT1, INPUT);
  digitalWriteFast(PIN_COUNTER_BIT0, LOW);
  digitalWriteFast(PIN_COUNTER_BIT1, LOW);

#if BRIDGE_WIRE_ROLE == BRIDGE_ROLE_MIDI_ONLY
  wire_set_mode(WIRE_TAKEOVER);
#else
  present_counter(0);
#endif

  USB.setManufacturer("little-scale");
  USB.setProduct("Chipbridge");
  MidiUSB.setName("Chipbridge MIDI");
  MidiUSB.begin();

  serial_midi_parser_reset(g_serialMidiParser);
#if SERIAL_MIDI_USE_PIO
  g_serialMidi.begin(SERIAL_MIDI_BAUD);
#else
  Serial1.setTX(PIN_SERIAL_MIDI_TX);
  Serial1.setRX(PIN_SERIAL_MIDI_RX);
  Serial1.begin(SERIAL_MIDI_BAUD);
#endif

  digitalWriteFast(PIN_STATUS_LED, HIGH);
}

void loop() {
  poll_usb_midi();
  poll_serial_midi();
  service_activity_led();
#if BRIDGE_WIRE_ROLE == BRIDGE_ROLE_MIDI_ONLY
  wire_set_mode(WIRE_TAKEOVER);
  if (g_wireMode == WIRE_TAKEOVER) takeover_idle_check();
#elif BRIDGE_WIRE_ROLE == BRIDGE_ROLE_AUTO
  if (g_wireMode == WIRE_TAKEOVER) {
    takeover_idle_check();
    if (!takeover_auto_active()) wire_set_mode(WIRE_COUNTER);
  }
#else
  wire_set_mode(WIRE_COUNTER);
#endif
}

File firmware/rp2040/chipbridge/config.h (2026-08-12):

// SPDX-License-Identifier: GPL-2.0-only
// config.h -- Chipbridge Pico-family USB/serial-MIDI firmware.
#pragma once

// Universal two-wire TRS data interface:
//
//   GP0 = DATA0 / counter bit 0 / takeover CLK -> TRS tip
//   GP1 = DATA1 / counter bit 1 / takeover DAT -> TRS ring
//   GND                                      -> TRS sleeve
//
// Each data line passes through the documented series resistor and BAT46 clamp
// before the GPIO. All outputs use low-or-release open-drain semantics; the
// console-side pull-up supplies logic high. Console adapters map the common TRS
// signals to each target connector without changing firmware polarity.
#define PIN_DATA0 0
#define PIN_DATA1 1
#define PIN_COUNTER_BIT0 PIN_DATA0
#define PIN_COUNTER_BIT1 PIN_DATA1

// External active-high firmware-alive LED. Connect GP7 through a 1 kΩ series
// resistor to the LED anode, and connect the LED cathode to GND. It turns on
// only after setup completes successfully.
#define PIN_STATUS_LED 7

// The same lines reverse roles for tracker SYNC: MIDI takeover.
#define PIN_MIDI_CLK PIN_COUNTER_BIT0
#define PIN_MIDI_DAT PIN_COUNTER_BIT1

// --- DIN / TRS MIDI input ---------------------------------------------------
// Both connector styles feed the same opto-isolated, non-inverted 31,250-baud
// UART input. The TX pin is configured by the Arduino core but is not connected.
// XIAO RP2040 exposes UART0 on D2/D3. The RP2040-Zero hardware model connects
// its 6N138 receiver output to GP13; use the same GP13 RX mapping on Pico-style
// boards so one firmware source retains a single non-XIAO pin convention.
#define SERIAL_MIDI_BAUD 31250
#if defined(ARDUINO_SEEED_XIAO_RP2040)
#define SERIAL_MIDI_USE_PIO 0
#define PIN_SERIAL_MIDI_TX 28  // D2 / GP28 -- leave unconnected
#define PIN_SERIAL_MIDI_RX 29  // D3 / GP29 <- MIDI receiver logic output
#else
#define SERIAL_MIDI_USE_PIO 1
#define PIN_SERIAL_MIDI_RX 13  // Pico physical pin 17 <- MIDI receiver output
#endif

// General releases select the wire role at runtime: MIDI clock/transport uses
// the counter, while channel-voice messages enter console-clocked takeover.
// Instrument releases override this at build time and keep takeover forced.
#define BRIDGE_ROLE_AUTO       0
#define BRIDGE_ROLE_MIDI_ONLY  1
#define BRIDGE_ROLE_CLOCK_ONLY 2
#ifndef BRIDGE_WIRE_ROLE
#define BRIDGE_WIRE_ROLE BRIDGE_ROLE_AUTO
#endif

#if BRIDGE_WIRE_ROLE != BRIDGE_ROLE_AUTO && \
    BRIDGE_WIRE_ROLE != BRIDGE_ROLE_MIDI_ONLY && \
    BRIDGE_WIRE_ROLE != BRIDGE_ROLE_CLOCK_ONLY
#error BRIDGE_WIRE_ROLE must be BRIDGE_ROLE_AUTO, BRIDGE_ROLE_MIDI_ONLY, or BRIDGE_ROLE_CLOCK_ONLY
#endif

#define MIDI_TAKEOVER_ENABLED (BRIDGE_WIRE_ROLE != BRIDGE_ROLE_CLOCK_ONLY)
#define TAKEOVER_AUTO_RELEASE_US 500000UL
#define TAKEOVER_IDLE_US      1500UL
#define MIDI_LED_OFF_US       25000UL   // inverse activity pulse: LED off for 25 ms
#define MIDI_LED_PERIOD_US    100000UL  // at most ten visible pulses per second
#define MIDI_EVTQ_SIZE        32

#if (MIDI_EVTQ_SIZE & (MIDI_EVTQ_SIZE - 1)) != 0
#error MIDI_EVTQ_SIZE must be a power of two
#endif

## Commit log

2026-08-12 Initial Chipbridge hardware and firmware release
    [chipbridge-atari2600-9pin.kicad_pcb, chipbridge-atari2600-9pin.kicad_sch, chipbridge-gg.kicad_pcb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]
2026-08-12 Add hardware bill of materials
    [BOM.csv, chipbridge-atari2600-9pin.kicad_sch, chipbridge-gg.kicad_sch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]
